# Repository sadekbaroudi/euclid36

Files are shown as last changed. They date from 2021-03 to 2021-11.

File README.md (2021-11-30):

# Support me!

I have spent a lot of time and money designing prototypes, testing, developing, etc. Any contributions would be greatly appreciated!

If you don't want to, or can't afford to support me, please send me a message to let me know you've built one, along with pictures. Also, feel free to submit a pull request with pictures into this repository. I'd be happy to showcase your build.

Reddit: /u/sadekbaroudi
Discord: sadekbaroudi#1258



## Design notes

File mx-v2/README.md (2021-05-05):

# euclid36

## The euclid36 supports the following:
* 36 keys
* Two rotary encoders
* 10 bottom facing LEDs for underglow
* 3 top facing LEDs for illumination in the center of the board
* Horizontal OLED near the top of the board
* 3 different types of Joysticks for mouse control
	* PS2/PS3/PS4 type joystick with click button (center of the board)
		* https://www.adafruit.com/product/512
	* 2 axis thumbstick
		* https://www.adafruit.com/product/2765
	* PSP type thumbstick
		* https://www.adafruit.com/product/444
	
### Placement of features:

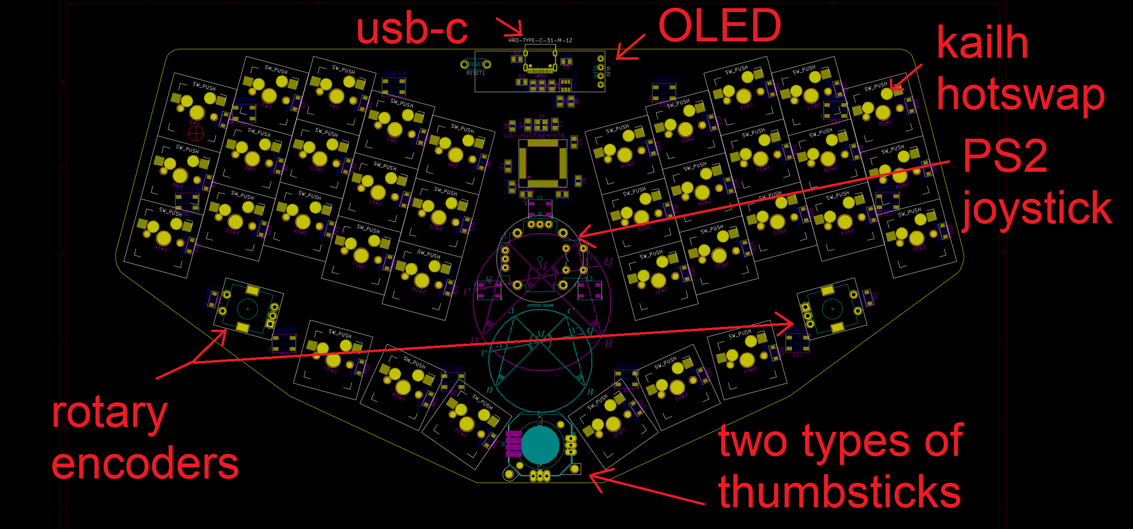
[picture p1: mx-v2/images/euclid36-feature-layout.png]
Euclid36 feature placement


### Print this file to test the layout. It is to scale

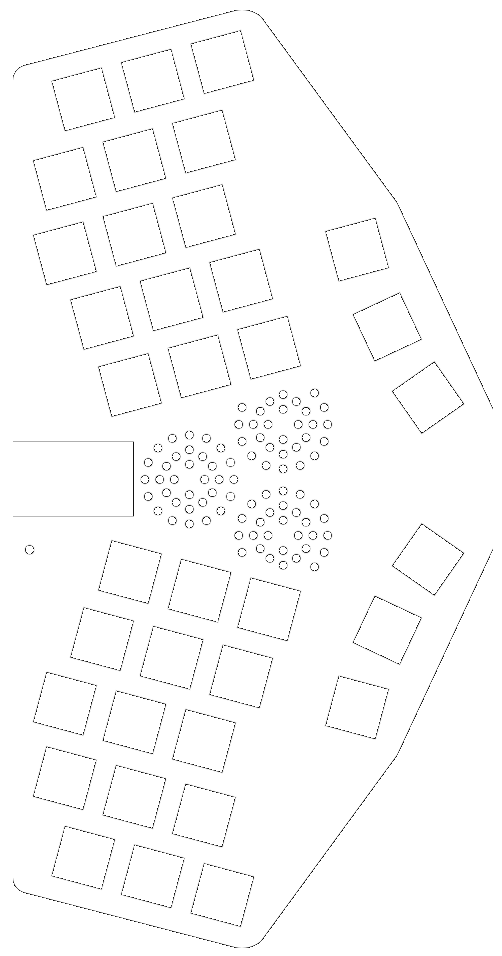
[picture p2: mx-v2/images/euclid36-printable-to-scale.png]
Euclid36 Printable


### 3d render

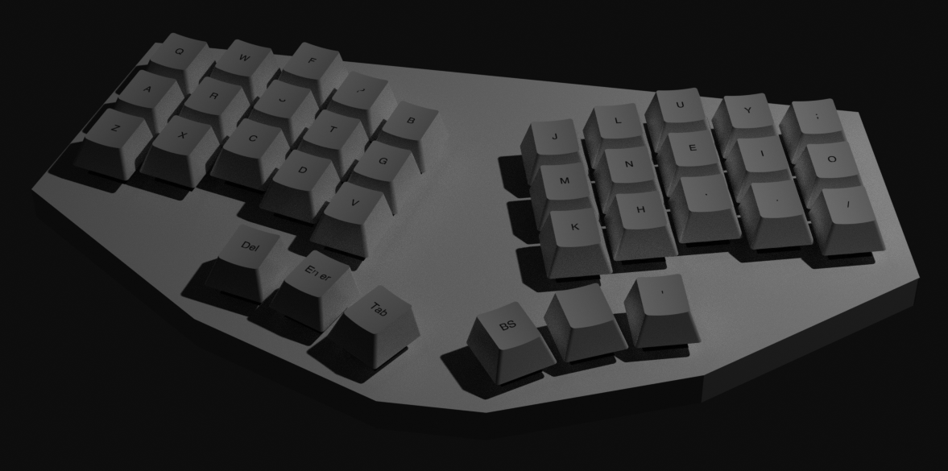
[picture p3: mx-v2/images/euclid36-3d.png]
Euclid36 3d render


### Layout

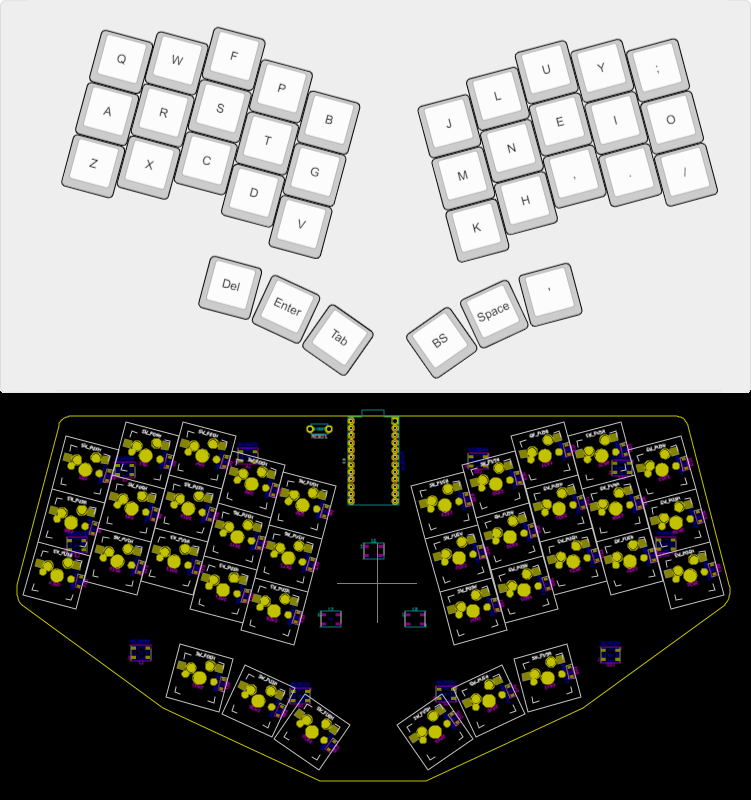
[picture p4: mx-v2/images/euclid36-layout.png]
Euclid36 layout


_At the time of creation, using Kicad 5.1.9 - This may not work with future versions_

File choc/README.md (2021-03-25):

First prototype

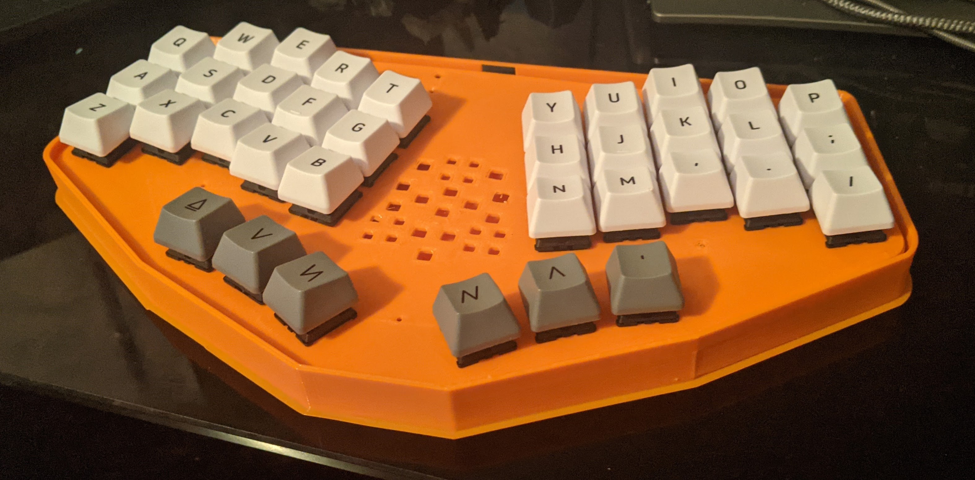
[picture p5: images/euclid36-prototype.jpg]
Euclid36 Prototype


3d render

Euclid36 3d render

Layout

Euclid36 layout

At the time of creation, using Kicad 5.1.9 - This may not work with future versions

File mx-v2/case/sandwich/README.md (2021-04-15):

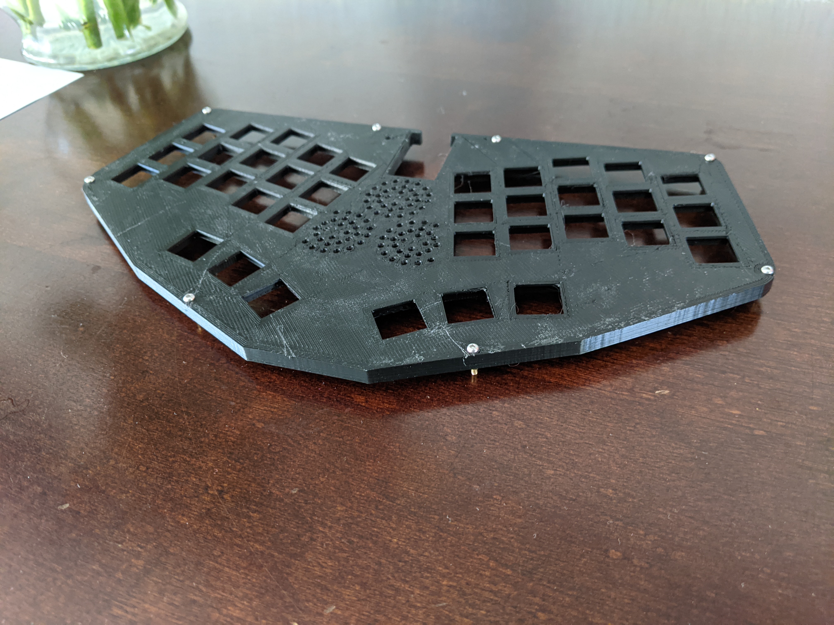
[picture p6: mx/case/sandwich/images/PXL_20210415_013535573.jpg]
Sandwich case image

Sandwich case image
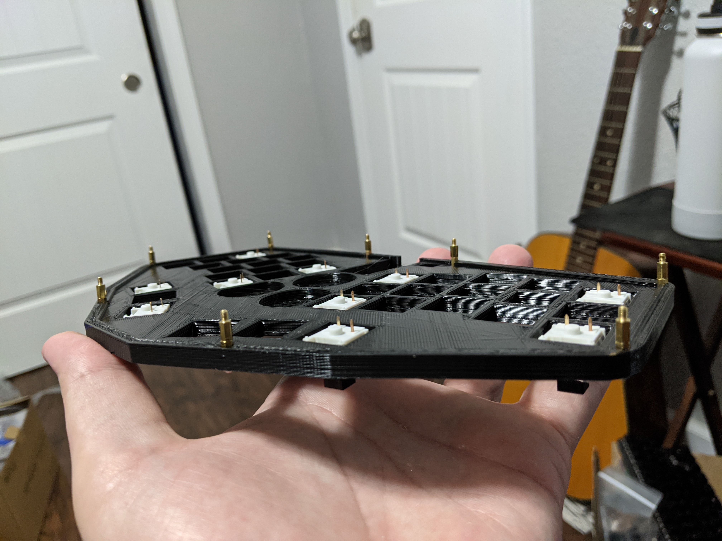
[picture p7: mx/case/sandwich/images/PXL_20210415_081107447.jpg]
Sandwich case image

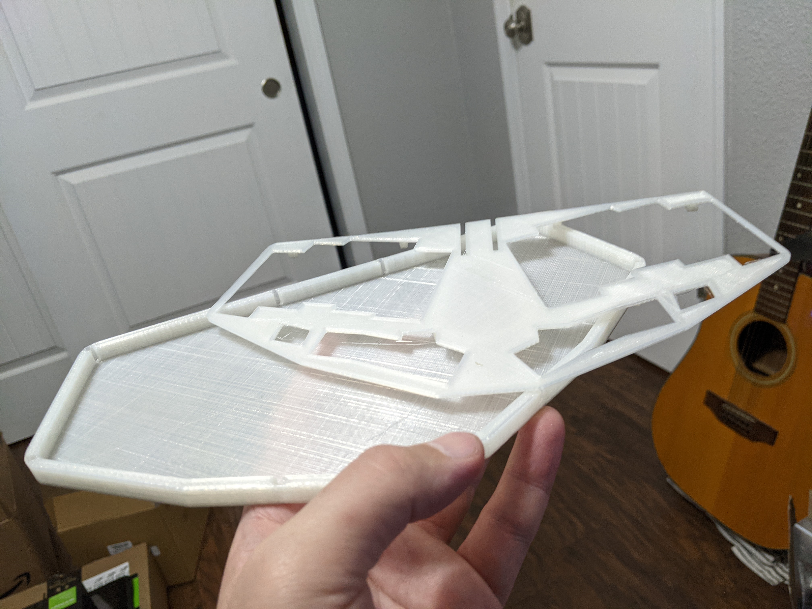
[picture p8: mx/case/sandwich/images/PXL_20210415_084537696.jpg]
Sandwich case image

Sandwich case image
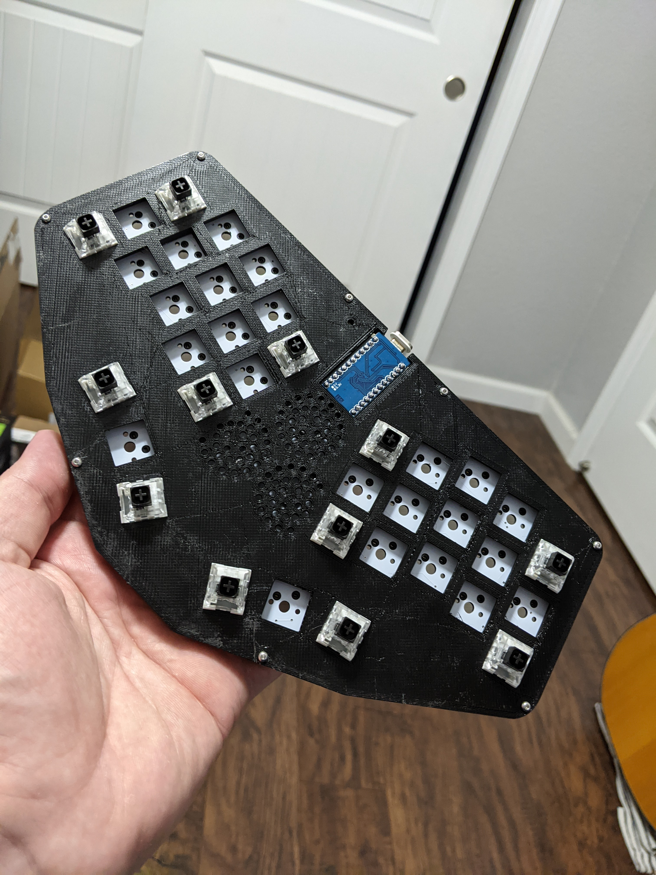
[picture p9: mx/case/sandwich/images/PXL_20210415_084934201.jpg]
Sandwich case image

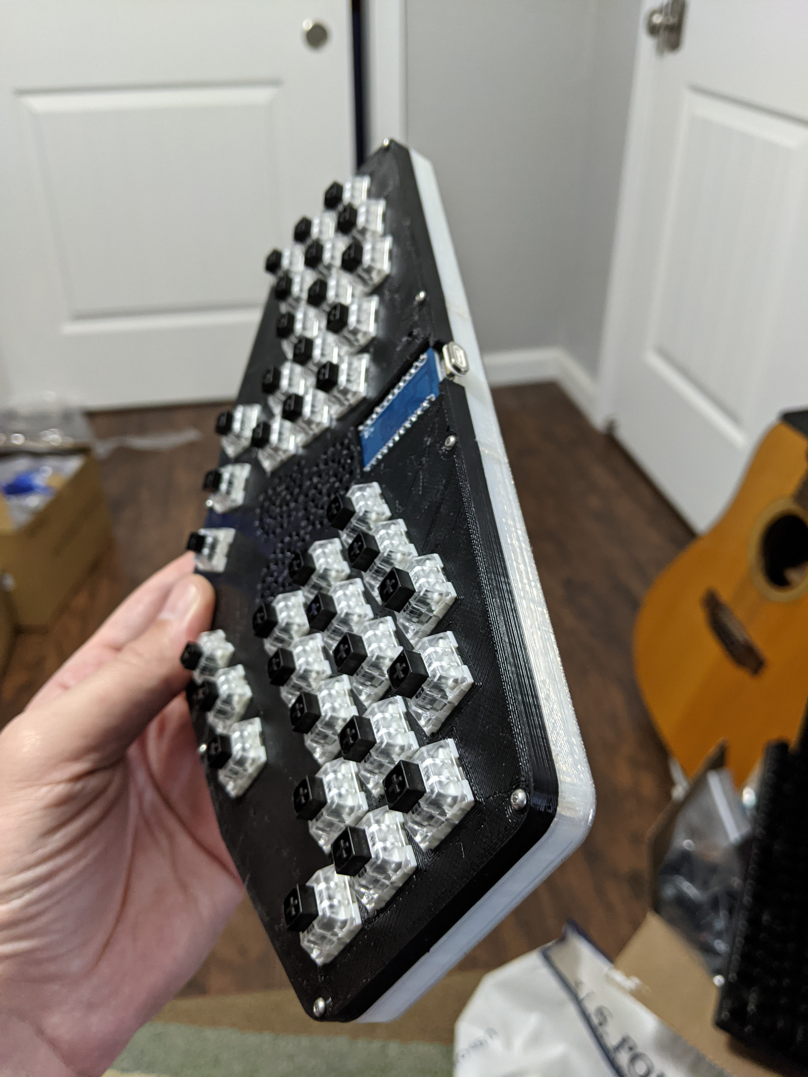
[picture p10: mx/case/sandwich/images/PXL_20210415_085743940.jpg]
Sandwich case image

Sandwich case image
Sandwich case image

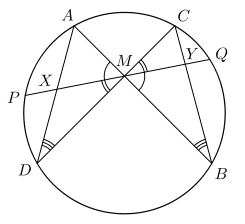
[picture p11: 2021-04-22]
mx-v2/images/euclidean-geometry.png

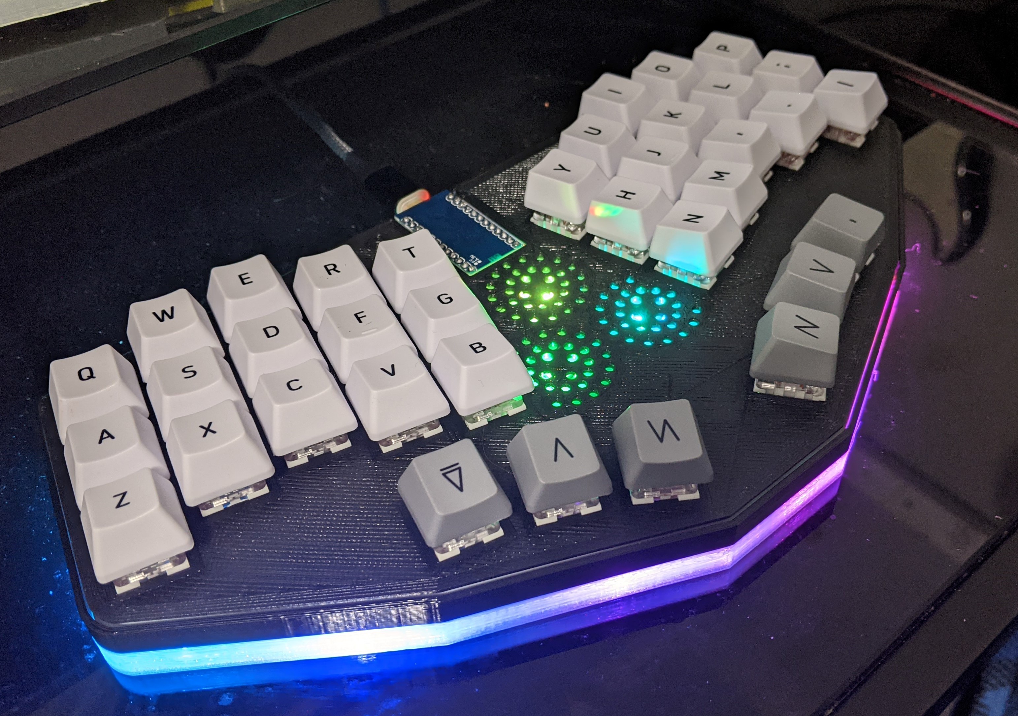
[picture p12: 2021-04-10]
mx-v2/images/euclid36-working-prototype.jpg

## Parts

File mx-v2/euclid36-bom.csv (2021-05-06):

Comment | Designator | Footprint | LCSC
1uF | C1 | Capacitor_SMD:C_0805_2012Metric_Pad1.18x1.45mm_HandSolder | C28323
0.1uF | C2,C3,C4 | Capacitor_SMD:C_0805_2012Metric_Pad1.18x1.45mm_HandSolder | C49678
10u | C5 | Capacitor_SMD:C_0805_2012Metric_Pad1.18x1.45mm_HandSolder | C15850
4.7n | C6,C9 | Capacitor_SMD:C_0805_2012Metric | C50131
22pF | C7,C8 | Capacitor_SMD:C_0805_2012Metric_Pad1.18x1.45mm_HandSolder | C1804
1N4148W | D1,D2,D3,D4,D5,D6,D7,D8,D9,D10,D11,D12,D14,D15,D16,D17,D18,D19,D20,D21,D22,D23,D25,D26,D27,D28,D29,D31,D32,D33,D34,D35,D37,D38,D39,D40,D41,D42 | Diode_SMD:D_SOD-123 | C727110
JOYSTICK_ANALOG_XY | JOY1 | adafruit-analog-thumbstick:JOYSTICK_ANALOG_MINITHM
WS2812B | L1,L2,L3,L4,L5,L6,L7,L8,L9,L10,L11,L12,L13 | LED_SMD:LED_WS2812B_PLCC4_5.0x5.0mm_P3.2mm | C114586
OLED | OL1 | _reviung-kbd:OLED_v2
10k | R1,R2 | Resistor_SMD:R_0805_2012Metric | C17414
1M | R3 | Resistor_SMD:R_0805_2012Metric | C17514
22R | R4,R5 | Resistor_SMD:R_0805_2012Metric | C17561
5.1k | R6,R7 | Resistor_SMD:R_0805_2012Metric | C27834
1.5K | R8 | Resistor_SMD:R_0805_2012Metric | C4310
SW_PUSH | RESET1 | _reviung-kbd:ResetSW_1side
JOYSTICK_THUMB | S1 | SparkFun-Switches:JOYSTICK
JOYSTICK_SLIDE | S2 | SparkFun-Switches:JOYSTICK-PSP1000
RotaryEncoder_Switch | SW1,SW7 | _reviung-kbd:RotaryEncoder_EC11 | C470750
SW_PUSH | SW2,SW3,SW4,SW5,SW6,SW8,SW9,SW10,SW11,SW12,SW14,SW15,SW16,SW17,SW18,SW19,SW20,SW21,SW22,SW23,SW25,SW26,SW27,SW28,SW29,SW31,SW32,SW33,SW34,SW35,SW37,SW38,SW39,SW40,SW41,SW42 | _reviung-kbd:MXOnly-1U-Hotswap
USBLC6-2SC6 | U1 | Package_TO_SOT_SMD:SOT-23-6 | C558442
ATmega32U4-AU | U2 | _reviung-kbd:ATMEGA32U4-AU | C44854
HRO-TYPE-C-31-M-12 | USB1 | _reviung-kbd:HRO-TYPE-C-31-M-12-Assembly | C165948
XTAL | Y1 | Crystal:Crystal_SMD_3225-4Pin_3.2x2.5mm | C13738

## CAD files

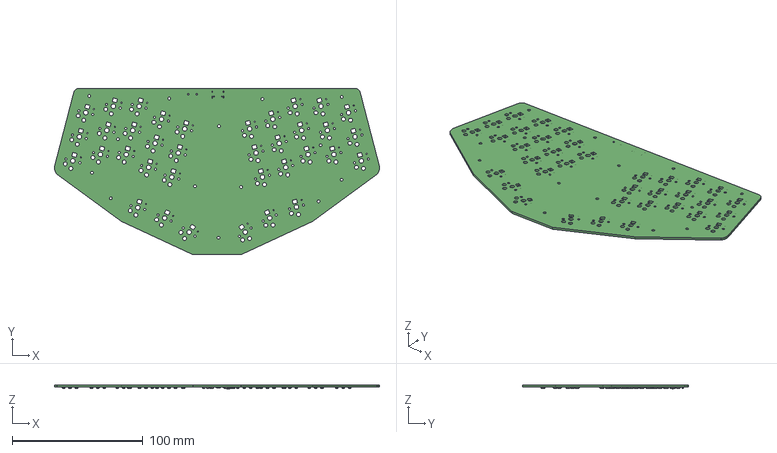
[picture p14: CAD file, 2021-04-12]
choc/case/euclid36.step
248.2 x 127.0 x 3.20 mm

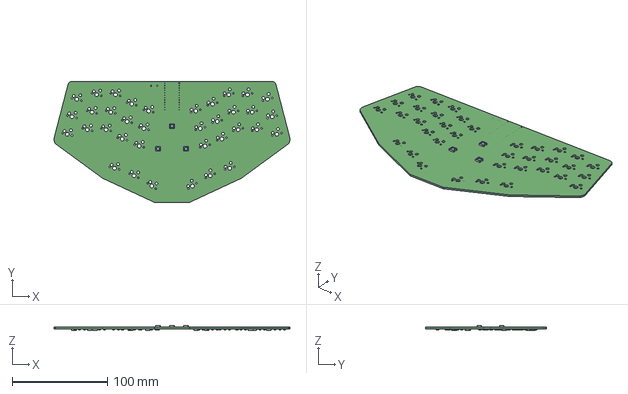
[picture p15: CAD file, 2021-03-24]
choc/euclid36-pcb.step
248.2 x 127.0 x 4.90 mm

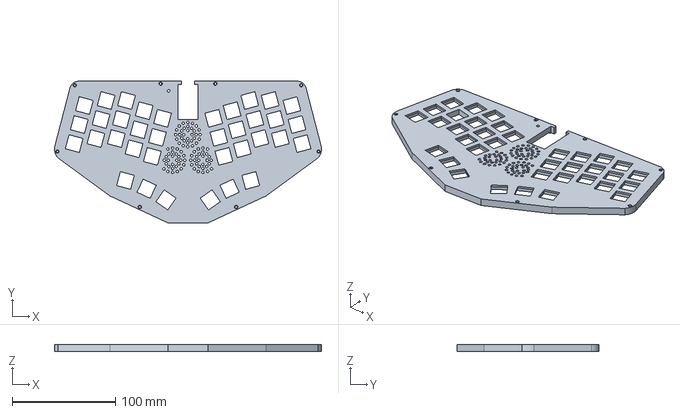
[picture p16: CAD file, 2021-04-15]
mx-v2/case/sandwich/euclid36-sandwich-case-top v4.step
258.2 x 137.0 x 6.40 mm

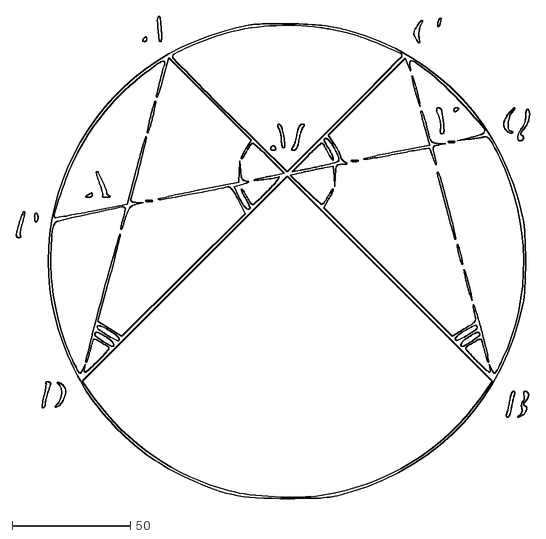
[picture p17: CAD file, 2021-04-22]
mx-v2/images/euclidean-geometry.dxf
217.3 x 204.1

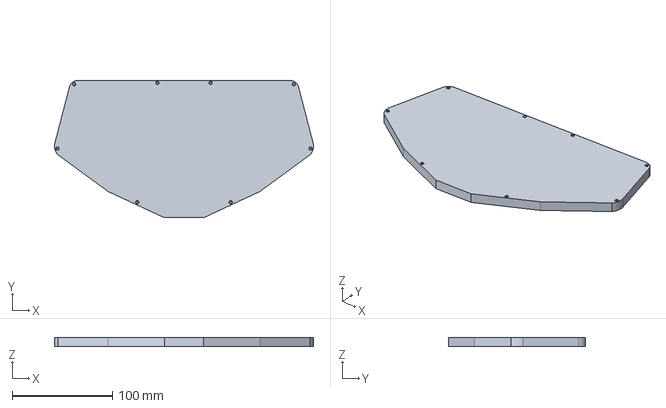
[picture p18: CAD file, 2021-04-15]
mx-v2/case/sandwich/euclid36-sandwich-case-bottom v3.step
258.2 x 137.0 x 8.60 mm

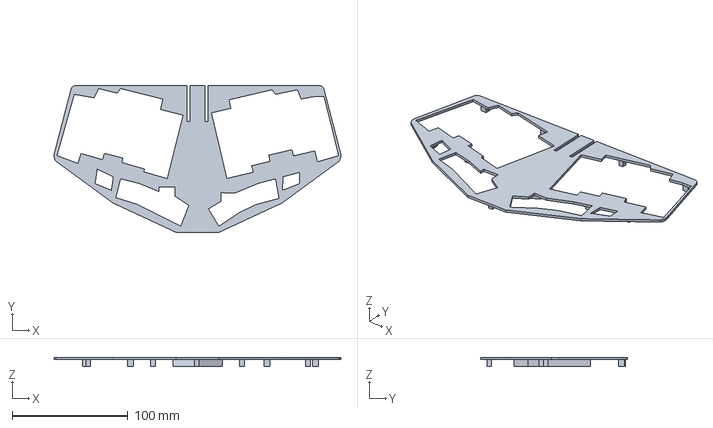
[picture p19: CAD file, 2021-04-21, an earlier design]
mx/case/euclid36-pcb-support v5.step
248.2 x 127.0 x 8.00 mm

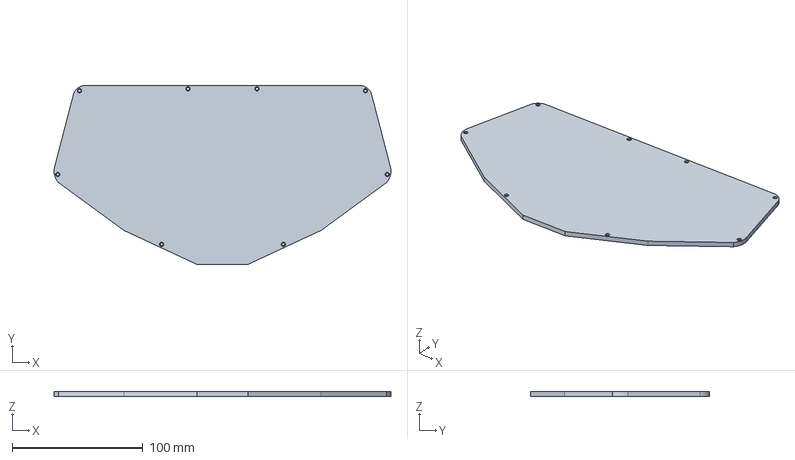
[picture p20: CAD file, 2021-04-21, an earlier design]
mx/case/sandwich/euclid36-sandwich-case-bottom-lp-no-underglow v1.step
258.2 x 137.0 x 3.60 mm

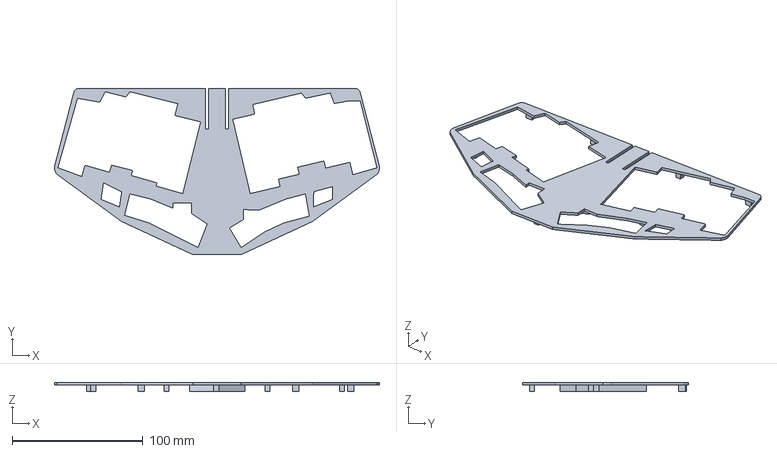
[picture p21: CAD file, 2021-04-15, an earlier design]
mx/case/sandwich/euclid36-sandwich-pcb-support v1.step
248.2 x 127.0 x 7.00 mm

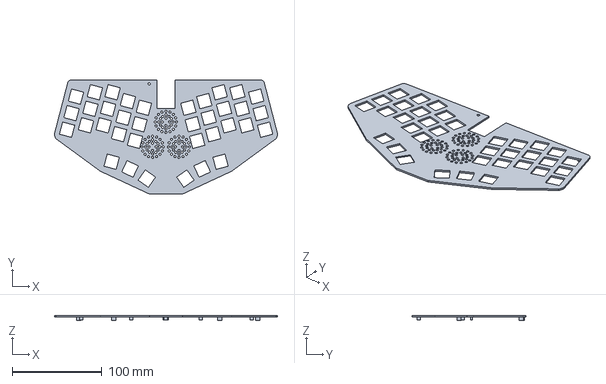
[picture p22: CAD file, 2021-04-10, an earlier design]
mx/case/euclid36-switch-plate v17.step
248.2 x 127.0 x 5.20 mm

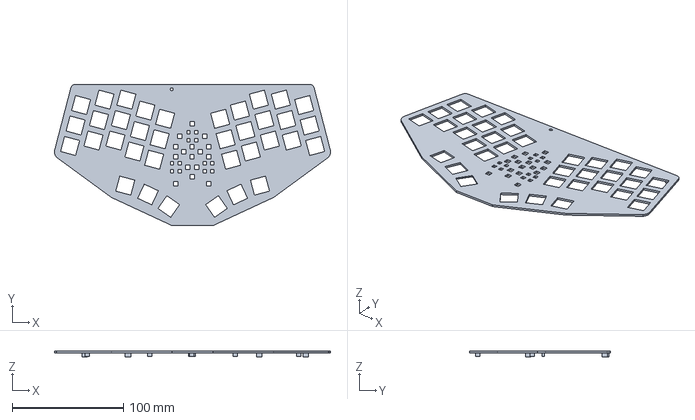
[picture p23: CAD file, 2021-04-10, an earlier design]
mx/case/euclid36-switch-plate v12.step
248.2 x 127.0 x 5.20 mm

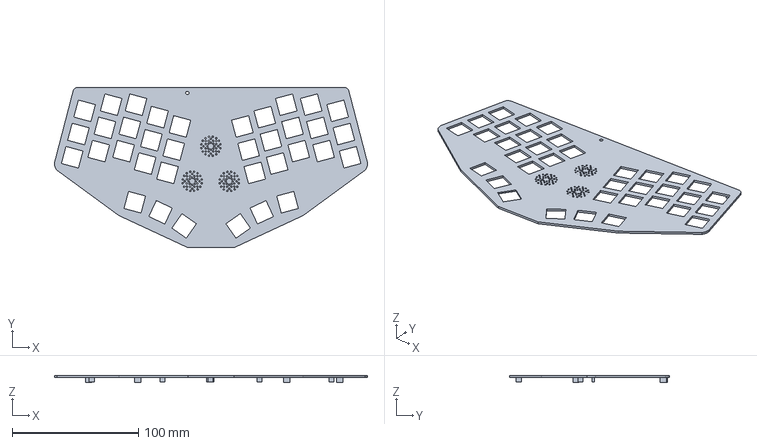
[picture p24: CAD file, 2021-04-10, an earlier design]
mx/case/euclid36-switch-plate v13.step
248.2 x 127.0 x 5.20 mm

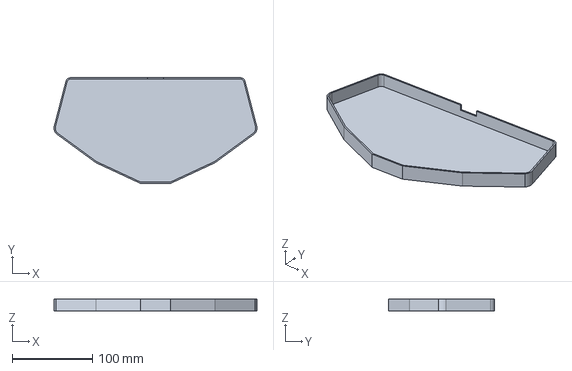
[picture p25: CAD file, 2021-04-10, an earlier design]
mx/case/euclid36-case v5.step
252.9 x 131.7 x 15.0 mm

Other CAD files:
mx-v2/euclid36.step
mx/case/euclid36-pcb-support v3.stl
mx/case/sandwich/euclid36-sandwich-case-top v3.step
mx/case/euclid36-pcb-support v4.step
mx/case/sandwich/euclid36-sandwich-case-bottom v2.step
mx/case/euclid36-switch-plate v14.step
mx-v2/case/sandwich/euclid36-sandwich-case-bottom v3.f3d
mx-v2/case/sandwich/euclid36-sandwich-case-bottom v3.stl
mx-v2/case/sandwich/euclid36-sandwich-case-top v4.f3d
mx-v2/case/sandwich/euclid36-sandwich-case-top v4.stl
mx/case/euclid36-case v4.f3d
mx/case/euclid36-case v4.step
mx/case/euclid36-case v4.stl
mx/case/euclid36-case v5.f3d
mx/case/euclid36-case v5.stl
mx/case/euclid36-pcb-support v4.f3d
mx/case/euclid36-pcb-support v4.stl
mx/case/euclid36-pcb-support v5.f3d
mx/case/euclid36-pcb-support.f3d
mx/case/euclid36-switch-plate v12.f3d
mx/case/euclid36-switch-plate v12.stl
mx/case/euclid36-switch-plate v13.f3d
mx/case/euclid36-switch-plate v13.stl
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

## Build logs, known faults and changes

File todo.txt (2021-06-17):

euclid36 mx-2
* the power has to run through the decoupling caps before the MCU
* (x) connect v-bus to 5v, the MCU has no power right now! I had to manually wire them together
* (x) connect 5v to vcc, the vcc line doesn't have power either! had to manually wire as well
* (x) the OLED is not connected to the right pins... It doesn't work. The data pins should be connected to pins 18 and 19 (SCL and SDA for QMK to use I2C to communicate with it)
* add pimoroni trackball support in the center... note that seems to use SCL and SDA, so the user may need to choose between the pimoroni or the OLED

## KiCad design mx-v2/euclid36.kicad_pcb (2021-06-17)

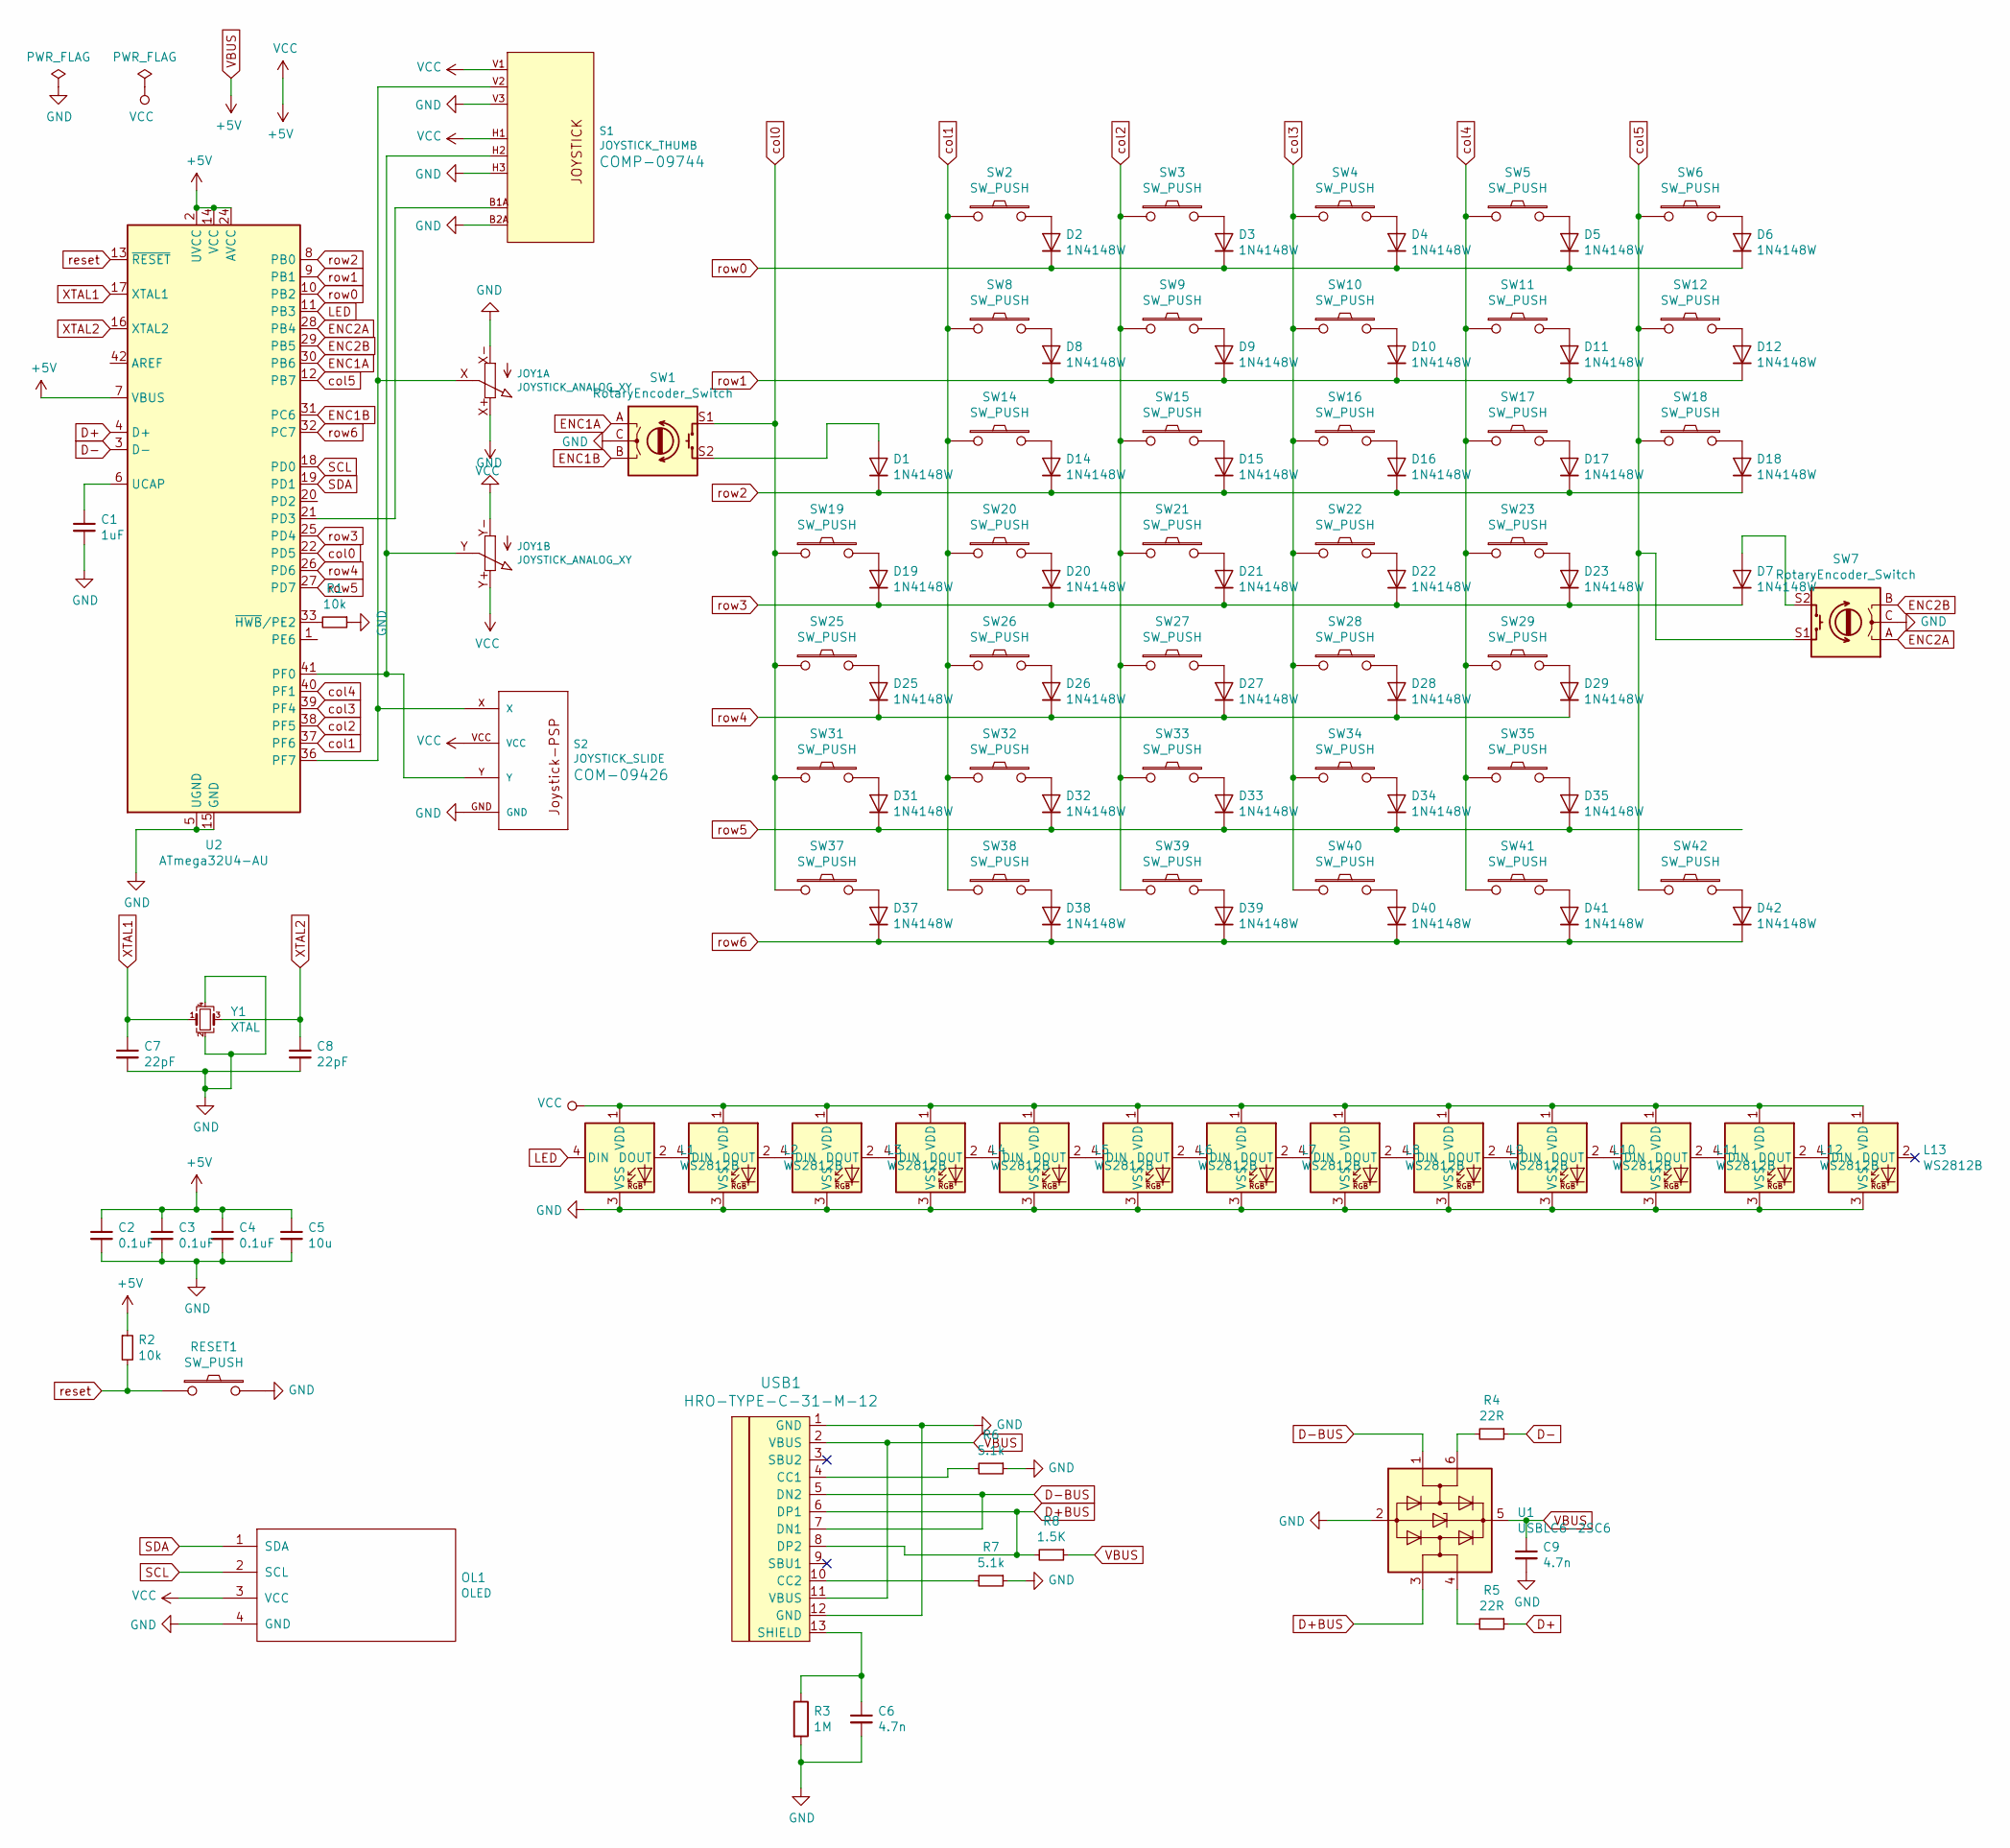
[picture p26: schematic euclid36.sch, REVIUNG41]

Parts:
C1: 1uF; C_0805_2012Metric_Pad1.18x1.45mm_HandSolder; LCSC C28323
C2, C3, C4: 0.1uF; C_0805_2012Metric_Pad1.18x1.45mm_HandSolder; LCSC C49678
C5: 10u; C_0805_2012Metric_Pad1.18x1.45mm_HandSolder; LCSC C15850
C6: 4.7n; C_0805_2012Metric; LCSC C50131
C7, C8: 22pF; C_0805_2012Metric_Pad1.18x1.45mm_HandSolder; LCSC C1804
C9: 4.7n; C_0805_2012Metric; LCSC C1744
D1, D2, D3, D4, D5, D6, D7, D8, D9, D10, D11, D12, D14, D15, D16, D17, D18, D19, D20, D21, D22, D23, D26, D27, D28, D29, D31, D32, D33, D34, D35, D37, D38, D39, D40, D41, D42: 1N4148W; D_SOD-123; LCSC C727110
D25: 1N4148W; D_SOD-123; LCSC C81598
JOY1: JOYSTICK_ANALOG_XY; JOYSTICK_ANALOG_MINITHM
L1, L2, L3, L4, L5, L6, L7, L8, L9, L10, L11, L12, L13: WS2812B; LED_WS2812B_PLCC4_5.0x5.0mm_P3.2mm; LCSC C114586
OL1: OLED; OLED_v2
R1, R2: 10k; R_0805_2012Metric; LCSC C17414
R3: 1M; R_0805_2012Metric; LCSC C17514
R4, R5: 22R; R_0805_2012Metric; LCSC C17561
R6, R7: 5.1k; R_0805_2012Metric; LCSC C27834
R8: 1.5K; R_0805_2012Metric; LCSC C4310
RESET1: SW_PUSH; ResetSW_1side
S1: JOYSTICK_THUMB; JOYSTICK
S2: JOYSTICK_SLIDE; JOYSTICK-PSP1000
SW1, SW7: RotaryEncoder_Switch; RotaryEncoder_EC11; LCSC C470750
SW2, SW3, SW4, SW5, SW6, SW8, SW9, SW10, SW11, SW12, SW14, SW15, SW16, SW17, SW18, SW19, SW20, SW21, SW22, SW23, SW25, SW26, SW27, SW28, SW29, SW31, SW32, SW33, SW34, SW35, SW37, SW38, SW39, SW40, SW41, SW42: SW_PUSH; MXOnly-1U-Hotswap
U1: USBLC6-2SC6; SOT-23-6; LCSC C558442
U2: ATmega32U4-AU; ATMEGA32U4-AU; LCSC C44854
USB1: HRO-TYPE-C-31-M-12; HRO-TYPE-C-31-M-12-Assembly; LCSC C165948
Y1: XTAL; Crystal_SMD_3225-4Pin_3.2x2.5mm; LCSC C13738

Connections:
D+: R5.1, U2.4 (D+)
D+BUS: R8.2, U1.3 (I/O2), USB1.6 (DP1), USB1.8 (DP2)
D-: R4.1, U2.3 (D-)
D-BUS: U1.1 (I/O1), USB1.5 (DN2), USB1.7 (DN1)
ENC1A: SW1.A, U2.30 (PB6)
ENC1B: SW1.B, U2.31 (PC6)
ENC2A: SW7.A, U2.28 (PB4)
ENC2B: SW7.B, U2.29 (PB5)
GND: C1.2, C2.2, C3.2, C4.2, C5.2, C6.2, C7.2, C8.2, C9.2, JOY1.X- (A), JOY1.Y- (A), L1.3 (VSS), L2.3 (VSS), L3.3 (VSS), L4.3 (VSS), L5.3 (VSS), L6.3 (VSS), L7.3 (VSS), L8.3 (VSS), L9.3 (VSS), L10.3 (VSS), L11.3 (VSS), L12.3 (VSS), L13.3 (VSS), OL1.4 (GND), R1.1, R3.2, R6.1, R7.1, RESET1.2, S1.B2A (SEL-), S1.H3 (H-), S1.V3 (V-), S2.GND, SW1.C, SW7.C, U1.2 (GND), U2.5 (UGND), U2.15 (GND), U2.23 (GND), U2.35 (GND), U2.43 (GND), USB1.1 (GND), USB1.12 (GND), Y1.2, Y1.4
LED: L1.4 (DIN), U2.11 (PB3)
unnamed: C1.1, U2.6 (UCAP)
unnamed: C6.1, R3.1, USB1.13 (SHIELD)
unnamed: D1.2 (A), SW1.S2
unnamed: D2.2 (A), SW2.2
unnamed: D3.2 (A), SW3.2
unnamed: D4.2 (A), SW4.2
unnamed: D5.2 (A), SW5.2
unnamed: D6.2 (A), SW6.2
unnamed: D7.2 (A), SW7.S2
unnamed: D8.2 (A), SW8.2
unnamed: D9.2 (A), SW9.2
unnamed: D10.2 (A), SW10.2
unnamed: D11.2 (A), SW11.2
unnamed: D12.2 (A), SW12.2
unnamed: D14.2 (A), SW14.2
unnamed: D15.2 (A), SW15.2
unnamed: D16.2 (A), SW16.2
unnamed: D17.2 (A), SW17.2
unnamed: D18.2 (A), SW18.2
unnamed: D19.2 (A), SW19.2
unnamed: D20.2 (A), SW20.2
unnamed: D21.2 (A), SW21.2
unnamed: D22.2 (A), SW22.2
unnamed: D23.2 (A), SW23.2
unnamed: D25.2 (A), SW25.2
unnamed: D26.2 (A), SW26.2
unnamed: D27.2 (A), SW27.2
unnamed: D28.2 (A), SW28.2
unnamed: D29.2 (A), SW29.2
unnamed: D31.2 (A), SW31.2
unnamed: D32.2 (A), SW32.2
unnamed: D33.2 (A), SW33.2
unnamed: D34.2 (A), SW34.2
unnamed: D35.2 (A), SW35.2
unnamed: D37.2 (A), SW37.2
unnamed: D38.2 (A), SW38.2
unnamed: D39.2 (A), SW39.2
unnamed: D40.2 (A), SW40.2
unnamed: D41.2 (A), SW41.2
unnamed: D42.2 (A), SW42.2
unnamed: JOY1.X (S), S1.V2 (V), S2.X, U2.36 (PF7)
unnamed: JOY1.Y (S), S1.H2 (H), S2.Y, U2.41 (PF0)
unnamed: L1.2 (DOUT), L2.4 (DIN)
unnamed: L2.2 (DOUT), L3.4 (DIN)
unnamed: L3.2 (DOUT), L4.4 (DIN)
unnamed: L4.2 (DOUT), L5.4 (DIN)
unnamed: L5.2 (DOUT), L6.4 (DIN)
unnamed: L6.2 (DOUT), L7.4 (DIN)
unnamed: L7.2 (DOUT), L8.4 (DIN)
unnamed: L8.2 (DOUT), L9.4 (DIN)
unnamed: L10.2 (DOUT), L11.4 (DIN)
unnamed: L9.2 (DOUT), L10.4 (DIN)
unnamed: L11.2 (DOUT), L12.4 (DIN)
unnamed: L12.2 (DOUT), L13.4 (DIN)
unnamed: R1.2, U2.33 (~HWB~/PE2)
unnamed: R4.2, U1.6 (I/O1)
unnamed: R5.2, U1.4 (I/O2)
unnamed: R6.2, USB1.4 (CC1)
unnamed: R7.2, USB1.10 (CC2)
unnamed: S1.B1A (SEL+), U2.21 (PD3)
SCL: OL1.2 (SCL), U2.18 (PD0)
SDA: OL1.1 (SDA), U2.19 (PD1)
VBUS: C2.1, C3.1, C4.1, C5.1, C9.1, JOY1.X+ (E), JOY1.Y+ (E), L1.1 (VDD), L2.1 (VDD), L3.1 (VDD), L4.1 (VDD), L5.1 (VDD), L6.1 (VDD), L7.1 (VDD), L8.1 (VDD), L9.1 (VDD), L10.1 (VDD), L11.1 (VDD), L12.1 (VDD), L13.1 (VDD), OL1.3 (VCC), R2.1, R8.1, S1.H1 (H+), S1.V1 (V+), S2.VCC, U1.5 (VBUS), U2.2 (UVCC), U2.7 (VBUS), U2.14 (VCC), U2.24 (AVCC), U2.34 (VCC), U2.44 (AVCC), USB1.2 (VBUS), USB1.11 (VBUS)
XTAL1: C7.1, U2.17 (XTAL1), Y1.1
XTAL2: C8.1, U2.16 (XTAL2), Y1.3
col0: SW1.S1, SW19.1, SW25.1, SW31.1, SW37.1, U2.22 (PD5)
col1: SW2.1, SW8.1, SW14.1, SW20.1, SW26.1, SW32.1, SW38.1, U2.37 (PF6)
col2: SW3.1, SW9.1, SW15.1, SW21.1, SW27.1, SW33.1, SW39.1, U2.38 (PF5)
col3: SW4.1, SW10.1, SW16.1, SW22.1, SW28.1, SW34.1, SW40.1, U2.39 (PF4)
col4: SW5.1, SW11.1, SW17.1, SW23.1, SW29.1, SW35.1, SW41.1, U2.40 (PF1)
col5: SW6.1, SW7.S1, SW12.1, SW18.1, SW42.1, U2.12 (PB7)
reset: R2.2, RESET1.1, U2.13 (~RESET)
row0: D2.1 (K), D3.1 (K), D4.1 (K), D5.1 (K), D6.1 (K), U2.10 (PB2)
row1: D8.1 (K), D9.1 (K), D10.1 (K), D11.1 (K), D12.1 (K), U2.9 (PB1)
row2: D1.1 (K), D14.1 (K), D15.1 (K), D16.1 (K), D17.1 (K), D18.1 (K), U2.8 (PB0)
row3: D7.1 (K), D19.1 (K), D20.1 (K), D21.1 (K), D22.1 (K), D23.1 (K), U2.25 (PD4)
row4: D25.1 (K), D26.1 (K), D27.1 (K), D28.1 (K), D29.1 (K), U2.26 (PD6)
row5: D31.1 (K), D32.1 (K), D33.1 (K), D34.1 (K), D35.1 (K), U2.27 (PD7)
row6: D37.1 (K), D38.1 (K), D39.1 (K), D40.1 (K), D41.1 (K), D42.1 (K), U2.32 (PC7)

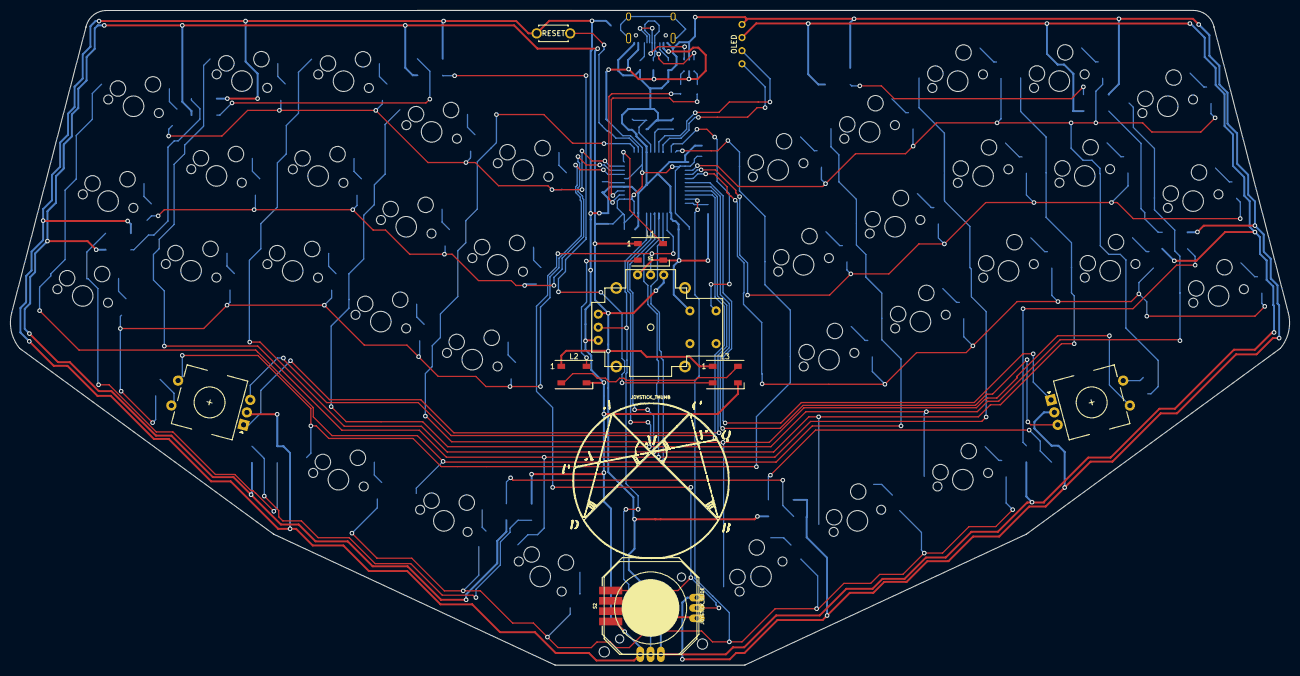
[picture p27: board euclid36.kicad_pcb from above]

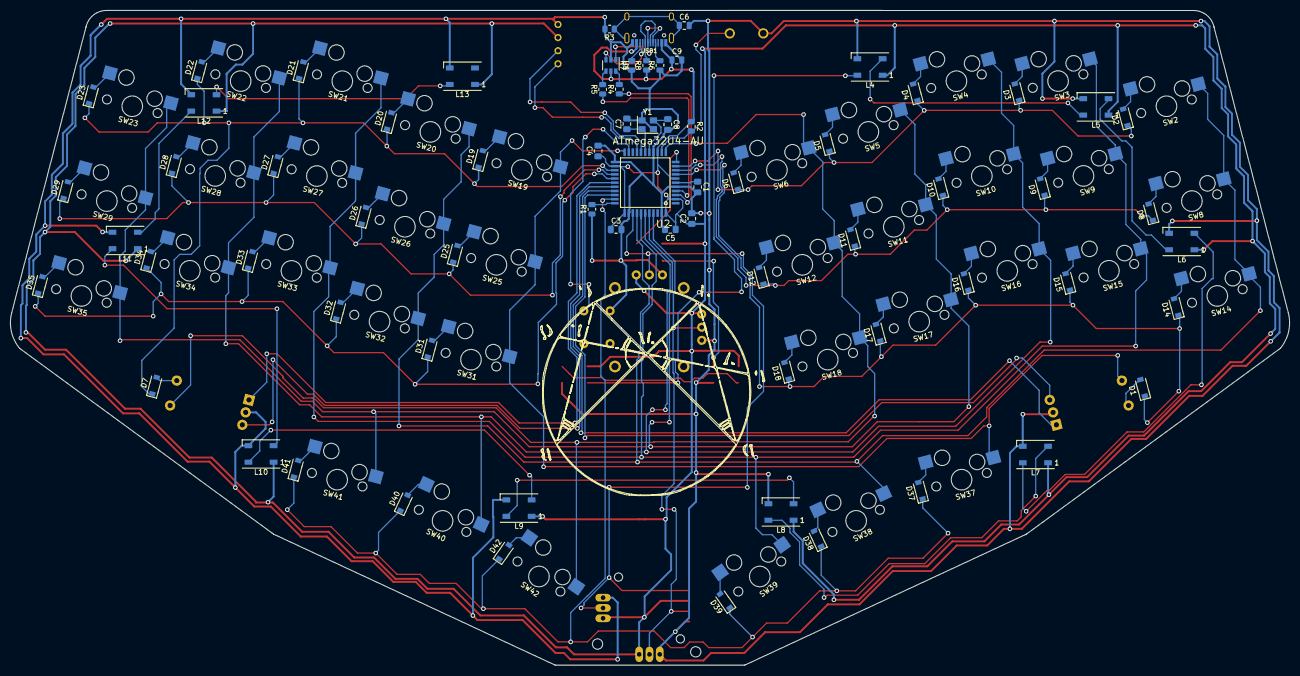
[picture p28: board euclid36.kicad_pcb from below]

Board: 2 copper layers, 248.2 x 127.0 mm, 115 parts (69 on the bottom side), 89 nets.

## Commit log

2021-03-16 let the chaos begin
    [euclid36.kicad_pcb, euclid36.sch]
2021-03-16 baseline schematic, need to add more switches
    [euclid36.sch]
2021-03-16 Assigned footprints to schematic symbols
    [euclid36.sch]
2021-03-17 Added all 36 keys
    [euclid36.sch]
2021-03-17 Updated key switch and diode labels
    [euclid36.sch]
2021-03-17 flipped some of the components, defined copper width for power
    [euclid36.kicad_pcb]
2021-03-17 moved into my own dir
    [euclid36.kicad_pcb, euclid36.sch]
2021-03-17 Added my own modified version of reviung41 that is basically what I want
    [pcb-top-plate.kicad_pcb, pcb-top-plate.sch, reviung41.kicad_pcb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]
2021-03-17 got rid of a bunch of unnecessary stuff
    [pcb-top-plate.kicad_pcb, pcb-top-plate.sch]
2021-03-17 moved pcb up one dir
    [reviung41.kicad_pcb, reviung41.sch]
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2021-03-17 Moved LEDs closer to bottom edge now that pcb dimensions extended
    [reviung41.kicad_pcb]
2021-03-17 Left edge of pcb was a little curved, fixed
    [reviung41.kicad_pcb]
2021-03-17 ever so slightly moved the bottom right led down
    [reviung41.kicad_pcb]
2021-03-17 flipped the diode from the front to the back and aligned
    [reviung41.kicad_pcb]
2021-03-19 New layout with bigger split, more pinky stagger, and better thumb cluster
    [reviung41.kicad_pcb, reviung41.sch]
2021-03-19 Rev02: Fixed a couple of switch positions and placed all the resistors
    [reviung41.kicad_pcb]
2021-03-19 centered some components more precisely
    [reviung41.kicad_pcb]
2021-03-20 added edge outline
    [reviung41.kicad_pcb]
2021-03-20 First round of working on rounting, wip
    [reviung41.kicad_pcb]
2021-03-21 completed all routing, still have unconnected stuff in DRC, need to fix
    [reviung41.kicad_pcb]
2021-03-21 Some major changes, replaced diodes with SOD123, fixed some routing, updated footprints to use different libraries
    [reviung41.kicad_pcb, reviung41.sch]
2021-03-22 euclid36 rev, sent to production...
    [reviung41.kicad_pcb, reviung41.sch]
2021-03-23 Removed unnecesary project files and completely renamed to euclid36
    [euclid36.kicad_pcb, euclid36.sch, reviung41.kicad_pcb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]
2021-03-23 Adding case files
    [euclid36-case v1.step, euclid36-case v1.stl]
2021-03-24 case and plate for euclid36
    [euclid36-switch-plate-v2.step, euclid36-switch-plate-v2.stl]
2021-03-24 Updated case and switch plates
    [euclid36-case-v2.f3d, euclid36-case-v2.step, euclid36-case-v2.stl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]
2021-03-24 add latest version of case and switchplate, as well as pcb model
    [euclid36-case-v3.f3d, euclid36-case-v3.step, euclid36-case-v3.stl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]
2021-03-27 new switchplate with legs to support the pressure of keypresses and an svg for laser cutting
    [euclid36-switch-plate-v8.f3d, euclid36-switch-plate-v8.step, euclid36-switch-plate-v8.stl]
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2021-03-30 Added one more hole for another stabilizer in the center
    [euclid36.kicad_pcb]
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2021-03-31 Added smt assembly support for jlcpcb.com, see bom and cpl csvs in gerber zip
    [euclid36.kicad_pcb]
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2021-03-31 moved main project into mx folder so I can create new versions of the keyboard in seperate folders
    [euclid36-case v1.step, euclid36-case v1.stl, euclid36-case-v2.f3d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]
2021-04-01 adding a new pcb design that is made for kailh choc switches, wip
    [euclid36-case v1.step, euclid36-case v1.stl, euclid36-case-v2.f3d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]
2021-04-02 Wired everything. Not too happy with it, but I think it works
    [euclid36.kicad_pcb]
2021-04-02 Small fixes
    [euclid36.kicad_pcb, euclid36.sch]
2021-04-06 Newest case to use without screws or standoffs, next comes pcb stand for this design
    [euclid36-case v4.f3d, euclid36-case v4.step, euclid36-case v4.stl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]
2021-04-07 new cases and pcb support
    [euclid36-case v5.f3d, euclid36-case v5.step, euclid36-case v5.stl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]
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2021-04-07 moved 2 LEDs slightly up as they were overlapping with hotswap sockets
    [euclid36.kicad_pcb]
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2021-04-10 complete, ready for fabrication, though might change mini usb to micro usb before doing so
    [euclid36-bom.csv, euclid36.dsn, euclid36.kicad_pcb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]
2021-04-12 Updated choc version to use usb-c. Almost done, still need to create a case / svgs
    [euclid36-B_Cu.gbr, euclid36-B_Mask.gbr, euclid36-B_SilkS.gbr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]
2021-04-12 Updated to include mounting holes and gerber update
    [euclid36-B_Cu.gbr, euclid36-B_Mask.gbr, euclid36-B_SilkS.gbr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]
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2021-04-15 Readme for sandwich case in the wrong spot
2021-04-21 added mx sandwich case and updated pcb to support OLED
    [euclid36-pcb-support v5.f3d, euclid36-pcb-support v5.step, euclid36-sandwich-case-bottom-lp-no-underglow v1.f3d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]
2021-04-22 v2 of euclid36 with integrated MCU, rotary encoders, and OLED
    [euclid36-B_Cu.gbr, euclid36-B_Mask.gbr, euclid36-B_SilkS.gbr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]
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2021-04-22 updated with drill holes for spacers
    [euclid36-B_Cu.gbr, euclid36-B_Mask.gbr, euclid36-B_SilkS.gbr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]
2021-04-22 Added one more spacer hole for top and bottom plates
    [euclid36-B_Cu.gbr, euclid36-B_Mask.gbr, euclid36-B_SilkS.gbr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]
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2021-04-27 Added support for two joysticks, but can't use both at the same time, as they share pins
    [euclid36.kicad_pcb]
2021-04-27 whoops, ran drc and had to fix a few things
    [euclid36.kicad_pcb]
2021-04-28 latest mx-v2, not sure what I changed
    [euclid36.sch]
2021-04-28 latest low pro choc keyboard
    [euclid36.kicad_pcb, euclid36.sch]
2021-04-28 accidentally wired my analog joysticks to digital inputs
    [euclid36.kicad_pcb, euclid36.sch]
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2021-05-05 added support for another joystick type, psp, as well as readme update with new feature layout image
    [euclid36.kicad_pcb, euclid36.sch]
2021-05-06 Proto V2 complete and ordered from jlcpcb.com
    [euclid36-B_Cu.gbr, euclid36-B_Mask.gbr, euclid36-B_SilkS.gbr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]
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2021-06-17 last revision had a few problems, fixed some, see todo.txt
    [euclid36.kicad_pcb, euclid36.sch]
2021-09-03 added verbiage to ask people to share builds and pictures with me
    [euclid36.sch]
